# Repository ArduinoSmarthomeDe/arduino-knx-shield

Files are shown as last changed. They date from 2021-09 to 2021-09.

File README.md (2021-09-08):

# Arduino Uno KNX TP-UART Shield

## Description

DIY shield for connecting the KNX bus to an Arduino Uno. Uses the first version of the Siemens TP-UART chip, which is very easy to solder by hand. In addition, there are 6 LEDs and 2 buttons on board for test purposes (e.g. for sending and receiving KNX group addresses).

The serial hardware interface (RX / TX), which is also used by the Arduino Uno from the USB port, can simply be separated from the TP-UART chip using a DIP switch. Alternatively, the serial interface of the TP-UART can be switched to software serial pins or is accessed on a connector.

*This is just a DIY board, so there is no official KNX stack to configure via the ETS software.*

**NOTICE: The shield fits best on an Arduino Uno with a micro USB connector. Otherwise it can lead to problems with USB Type A connector.**

## Preview

A little look at the finished circuit board (3D model):

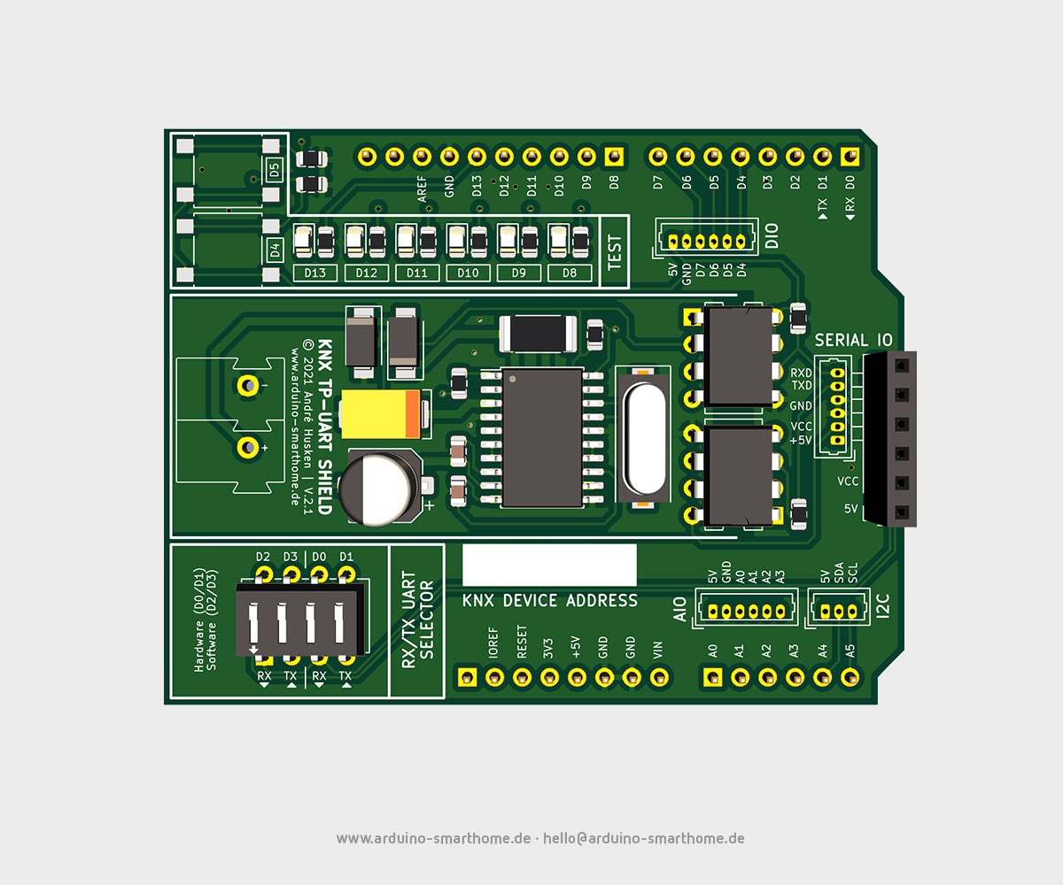
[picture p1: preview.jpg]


## Parts

Some parts are a hard to come by, so here is a short overview of known distributors (no affiliates).

| Item | Part | Link  |
| --- |:---:| ----- |
| U1 | Siemens TP-Uart | http://www.opternus.com/de/siemens/knx-chipset/knx-transceiver-ics-tp-uart-fze1066.html |
| D2 | P4SMAJ43A | https://www.reichelt.de/tvs-diode-unidirektional-43-v-400-w-do-214ac-sma-p4smaj43a-p272910.html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 |
| D3 | RND US1M-AT | https://www.reichelt.de/gleichrichterdiode-1000-v-1-a-do-214ac-sma-us-1m-p146618.html?&trstct=pos_0&nbc=1 |
| KNX Pins  | WAGO 243-131				 | https://www.reichelt.de/wago-loetstifte-fuer-buchsenklemmen-wago-243-131-p67263.html?&trstct=pos_0&nbc=1 |

## Layout & Production 

You can find all the open data here as a [KiCad](http://kicad.github.io) project. You can find all the necessary dependencies such as footprints or libraries in the folder **KiCad Symbols & Footprints**.

The *Gerber files* for the production of the board can be found here under **releases**.

## License

The MIT License (MIT)

Copyright (c) 2021 André Husken hello@arduino-smarthome.de

Permission is hereby granted, free of charge, to any person obtaining a copy of this software and associated documentation files (the "Software"), to deal in the Software without restriction, including without limitation the rights to use, copy, modify, merge, publish, distribute, sublicense, and/or sell copies of the Software, and to permit persons to whom the Software is furnished to do so, subject to the following conditions:

The above copyright notice and this permission notice shall be included in all copies or substantial portions of the Software.

THE SOFTWARE IS PROVIDED "AS IS", WITHOUT WARRANTY OF ANY KIND, EXPRESS OR IMPLIED, INCLUDING BUT NOT LIMITED TO THE WARRANTIES OF MERCHANTABILITY, FITNESS FOR A PARTICULAR PURPOSE AND NONINFRINGEMENT. IN NO EVENT SHALL THE AUTHORS OR COPYRIGHT HOLDERS BE LIABLE FOR ANY CLAIM, DAMAGES OR OTHER LIABILITY, WHETHER IN AN ACTION OF CONTRACT, TORT OR OTHERWISE, ARISING FROM, OUT OF OR IN CONNECTION WITH THE SOFTWARE OR THE USE OR OTHER DEALINGS IN THE SOFTWARE.

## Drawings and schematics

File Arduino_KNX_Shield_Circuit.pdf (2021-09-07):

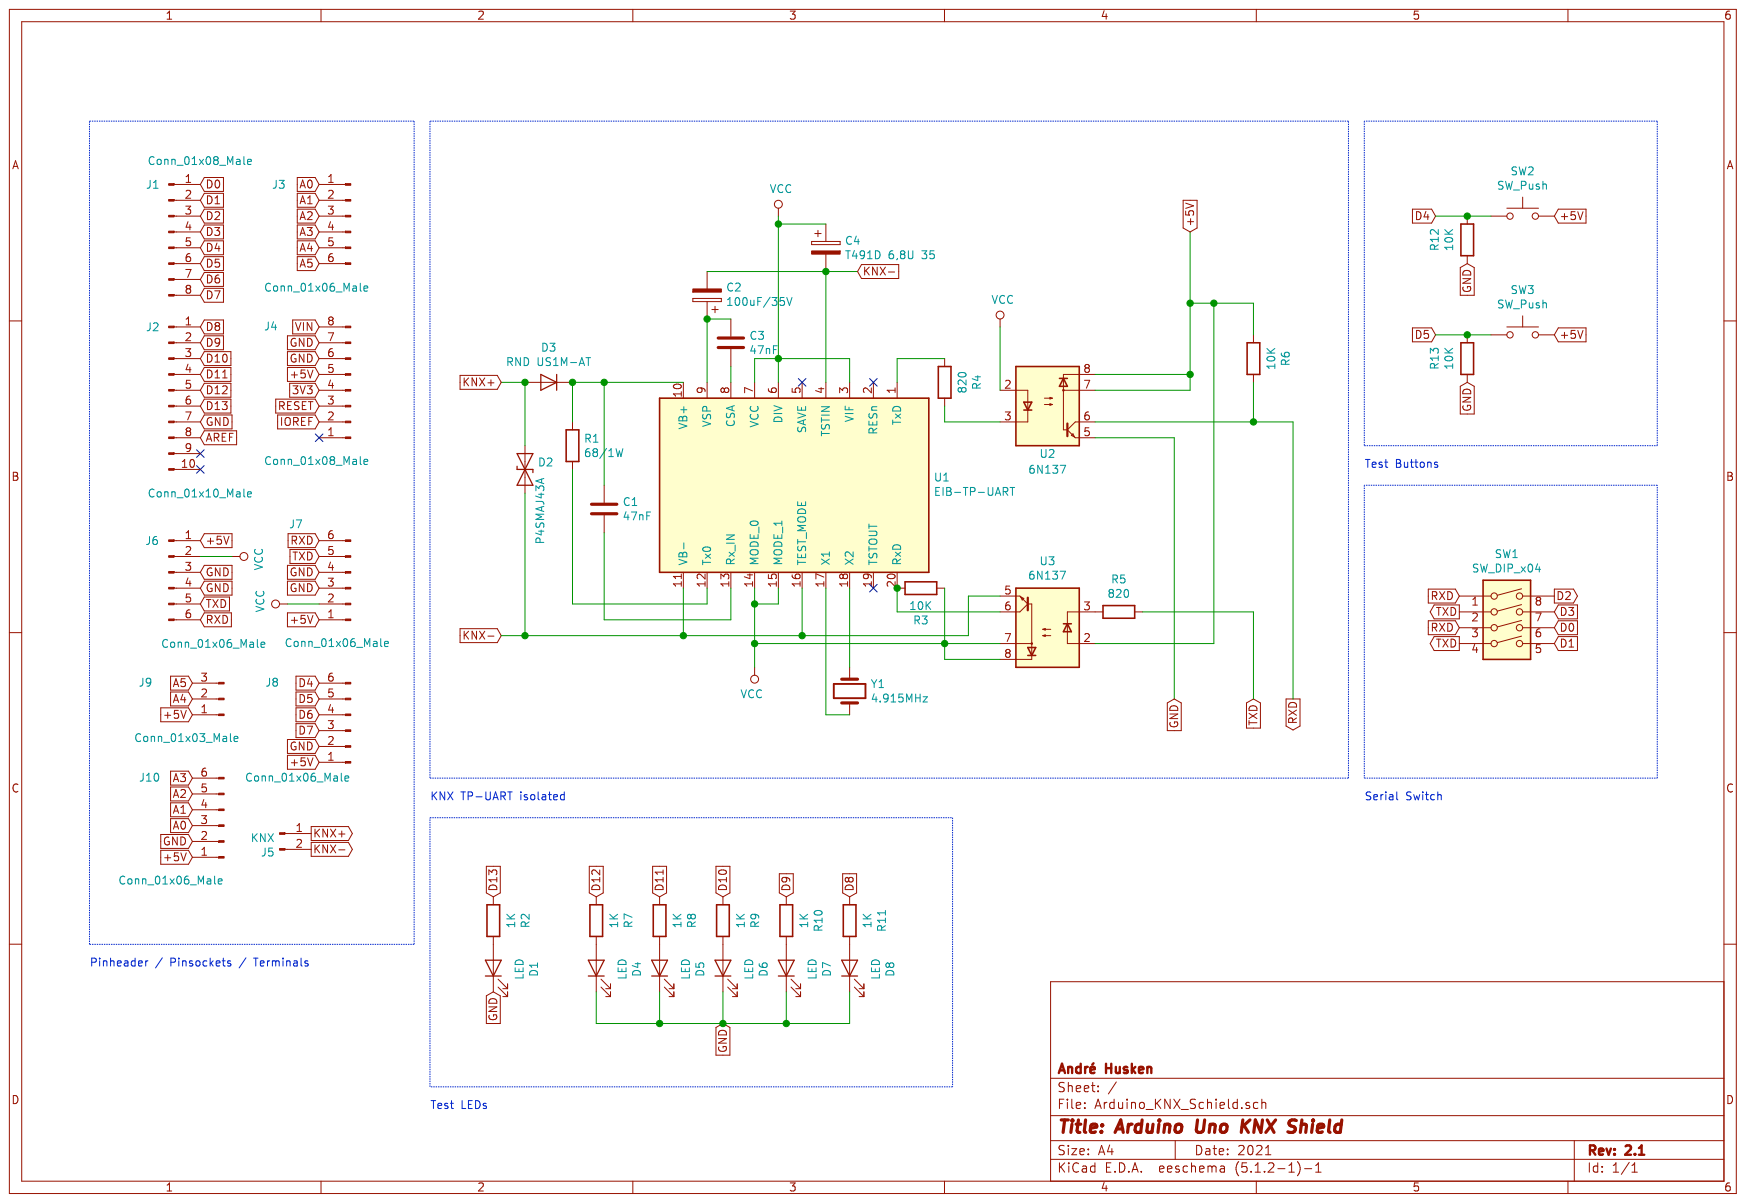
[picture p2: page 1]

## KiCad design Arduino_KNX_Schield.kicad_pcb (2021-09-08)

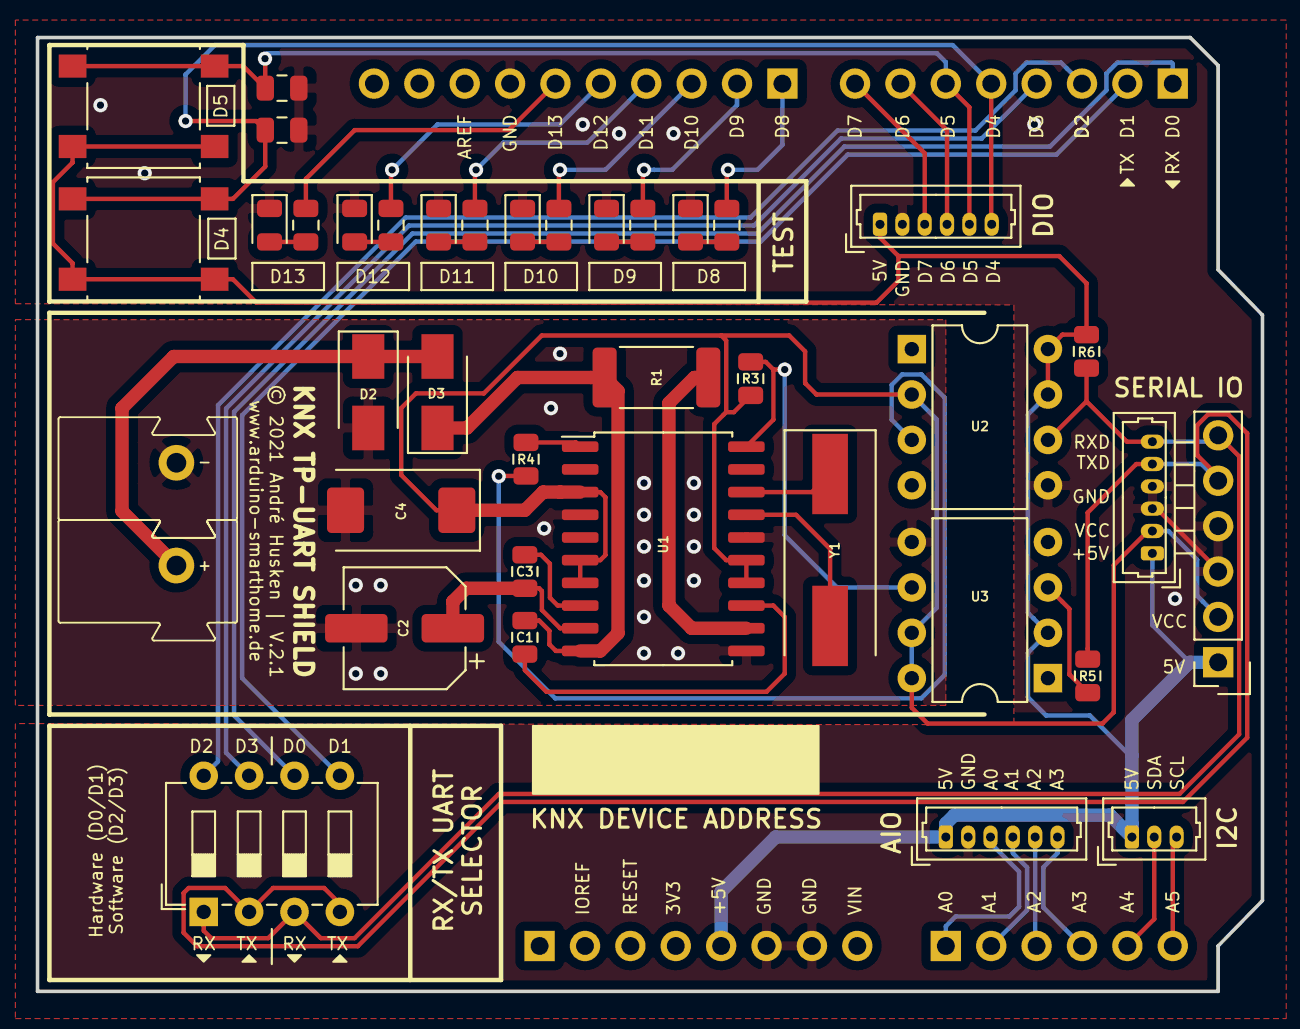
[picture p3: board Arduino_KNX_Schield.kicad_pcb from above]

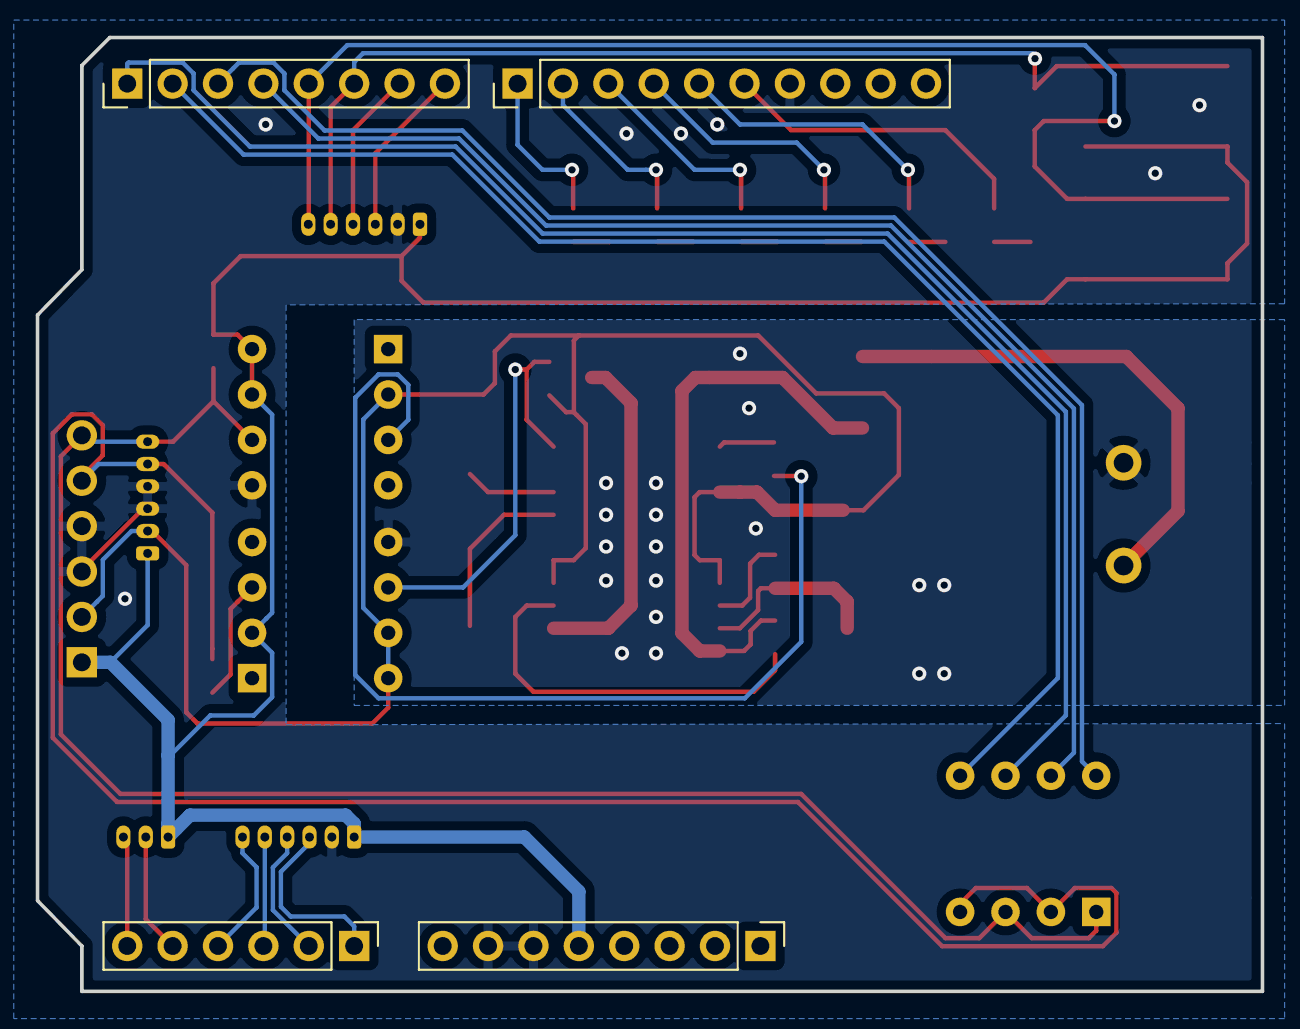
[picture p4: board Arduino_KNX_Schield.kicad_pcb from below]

Board: 2 copper layers, 68.5 x 53.4 mm, 42 parts (4 on the bottom side), 44 nets.

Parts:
C1, C3: 47nF; C_0805_2012Metric
C2: 100uF/35V; CP_Elec_6.3x7.7
C4: T491D 6,8U 35; CP_EIA-7343-20_Kemet-V
D1, D4, D5, D6, D7, D8: LED; LED_0805_2012Metric
D2: P4SMAJ43A; D_SMA
D3: RND US1M-AT; D_SMA
J1, J4: Conn_01x08_Male; PinHeader_1x08_P2.54mm_Vertical
J2: Conn_01x10_Male; PinHeader_1x10_P2.54mm_Vertical
J3: Conn_01x06_Male; PinHeader_1x06_P2.54mm_Vertical
J5: KNX; Wago_KNX_243-211_1x02_P5.75mm_Vertical_Top
J6, J8, J10: Conn_01x06_Male; Molex_PicoBlade_53047-0610_1x06_P1.25mm_Vertical
J7: Conn_01x06_Male; PinSocket_1x06_P2.54mm_Vertical
J9: Conn_01x03_Male; Molex_PicoBlade_53047-0310_1x03_P1.25mm_Vertical
R1: 68/1W; R_2512_6332Metric
R2, R7, R8, R9, R10, R11: 1K; R_0805_2012Metric
R3, R6, R12, R13: 10K; R_0805_2012Metric
R4, R5: 820; R_0805_2012Metric
SW1: SW_DIP_x04; SW_DIP_SPSTx04_Slide_6.7x11.72mm_W7.62mm_P2.54mm_LowProfile
SW2, SW3: SW_Push; SW_SPST_B3S-1000
U1: EIB-TP-UART; SOIC-20W_7.5x12.8mm_P1.27mm
U2, U3: 6N137; DIP-8_W7.62mm
Y1: 4.915MHz; Crystal_SMD_HC49-SD

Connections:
+5V: J4.5, J6.1, J7.1, J8.1, J9.1, J10.1, R6.2, SW2.2, SW3.2, U2.7, U2.8, U3.2
A0: J3.1, J10.3
A1: J3.2, J10.4
A2: J3.3, J10.5
A3: J3.4, J10.6
A4: J3.5, J9.2
A5: J3.6, J9.3
D0: J1.1, SW1.6
D1: J1.2, SW1.5
D2: J1.3, SW1.8
D3: J1.4, SW1.7
D4: J1.5, J8.6, R12.1, SW2.1
D5: J1.6, J8.5, R13.1, SW3.1
D6: J1.7, J8.4
D7: J1.8, J8.3
D8: J2.1, R11.2
D9: J2.2, R10.2
D10: J2.3, R9.2
D11: J2.4, R8.2
D12: J2.5, R7.2
D13: J2.6, R2.2
GND: D1.1, D4.1, D5.1, D6.1, D7.1, D8.1, J2.7, J4.6, J4.7, J6.3, J6.4, J7.3, J7.4, J8.2, J10.2, R12.2, R13.2, U2.5
KNX+: D2.1, D3.2, J5.1
KNX-: C2.2, C4.2, D2.2, J5.2, U1.4, U1.11, U1.16, U3.5
unnamed: C1.1, D3.1, R1.1, U1.10
unnamed: C1.2, U1.13
unnamed: C2.1, C3.1, U1.9
unnamed: C3.2, U1.8
unnamed: D1.2, R2.1
unnamed: D4.2, R7.1
unnamed: D5.2, R8.1
unnamed: D6.2, R9.1
unnamed: D7.2, R10.1
unnamed: D8.2, R11.1
unnamed: R1.2, U1.12
unnamed: R3.1, U1.20, U3.6
unnamed: R4.1, U2.3
unnamed: R4.2, U1.1
unnamed: R5.2, U3.3
unnamed: U1.17, Y1.2
unnamed: U1.18, Y1.1
RXD: J6.6, J7.6, R6.1, SW1.1, SW1.3, U2.6
TXD: J6.5, J7.5, R5.1, SW1.2, SW1.4
VCC: C4.1, J6.2, J7.2, R3.2, U1.3, U1.6, U1.7, U1.14, U1.15, U2.2, U3.7, U3.8

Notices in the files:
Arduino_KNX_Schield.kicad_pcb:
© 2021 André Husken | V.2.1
